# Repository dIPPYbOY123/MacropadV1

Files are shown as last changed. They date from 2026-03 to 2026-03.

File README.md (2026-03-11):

# MacropadV1

MacropadV1 is a custom-designed 6-key mechanical macropad featuring a rotary encoder, an OLED display, and RGB lighting. It's powered by the Seeed Xiao RP2040 and running KMK firmware.

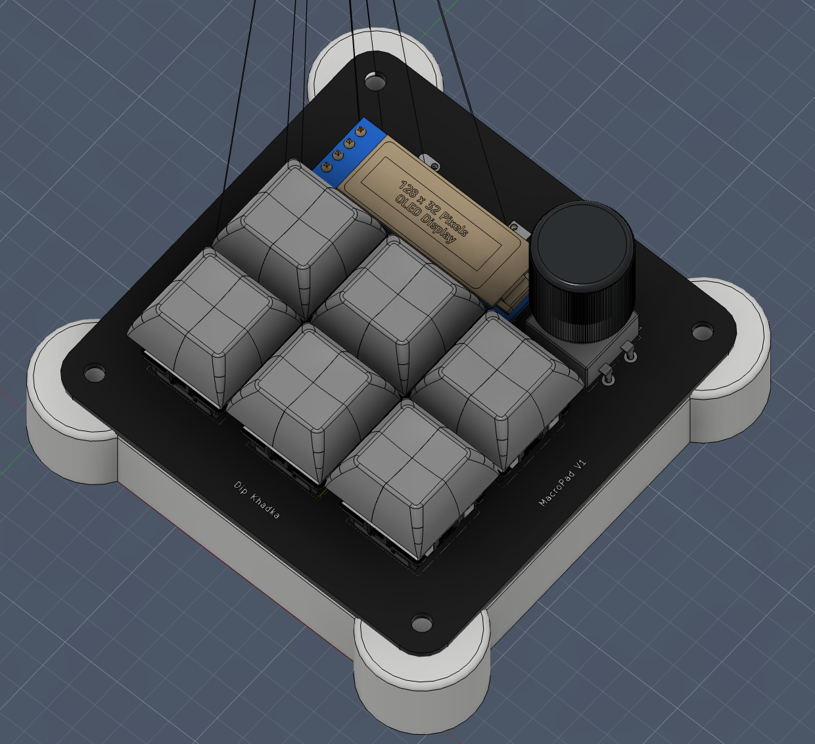
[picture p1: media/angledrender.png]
Macropad Render


## Features

- **6 Mechanical Switches**: MX-style switches.
- **Rotary Encoder**: Smooth scrolling and volume control.
- **OLED Display (128x32)**: Real-time feedback on layers, status, and custom animations.
- **7 Addressable RGB LEDs**: Fully customizable underglow and per-key lighting.
- **Compact Design**: Custom-designed 3D printable case for minimalistic vibe.
- **KMK Firmware**: Easily customizable using Python.

## Bill of Materials (BOM)

| Component | Quantity | Specification |
| :--- | :---: | :--- |
| **Microcontroller** | 1 | Seeed Xiao RP2040 |
| **Switches** | 6 | MX-style Mechanical Switches |
| **Keycaps** | 6 | MX-compatible Keycaps |
| **Rotary Encoder** | 1 | EC11 Encoder with Push Button |
| **OLED Display** | 1 | 0.91" 128x32 I2C OLED |
| **Diodes** | 6 | 1N4148 Through-hole Diodes |
| **RGB LEDs** | 7 | SK6812 Mini-E |
| **PCB** | 1 | Custom MacropadV1 PCB |
| **Hardware** | 4 | M3 x 16mm Screws |
| **Case** | 1 | 3D Printed Case |

### Case Design
Designed in Autodesk Fusion, the project includes a custom 3D printable case designed for a sleek, low-profile look.

| Case Angled View | Case Back View |
| :---: | :---: |
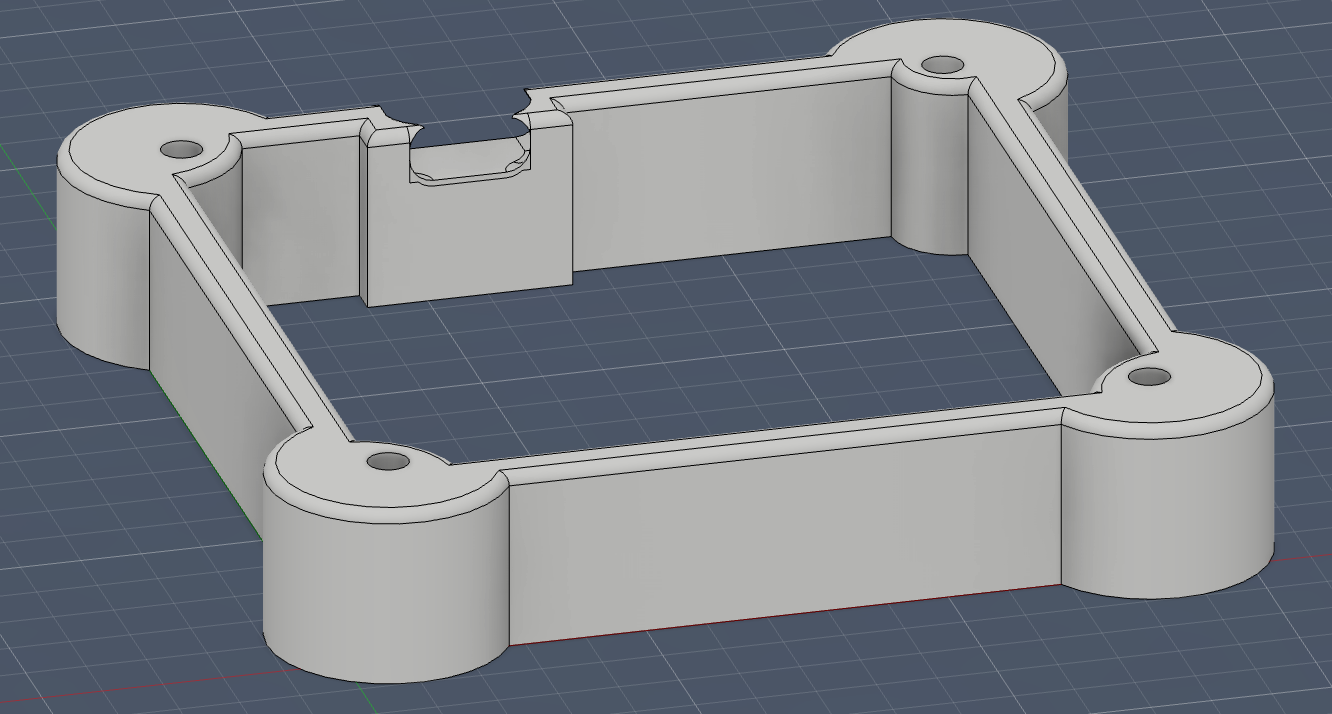
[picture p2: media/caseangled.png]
Case Angled View
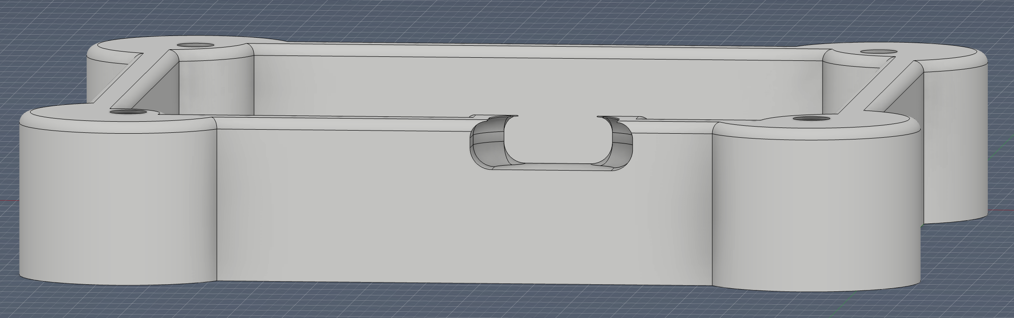
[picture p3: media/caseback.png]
Case Back View
|  |  |

## Firmware

MacropadV1 runs on **KMK Firmware**, a feature-rich keyboard firmware written in CircuitPython.

### Keymap Configuration
The default keymap includes dedicated layers for media control, macros (Copy/Paste/Save), and RGB lighting effects.

- **Layer 0**: Media controls, Copy/Paste/Cut macros, Screen Snipping.
- **Layer 1**: Navigation and Select All macros.
- **Layer 2**: RGB Lighting controls (Mode, Brightness, Color).

The rotary encoder is mapped to volume control by default.

## PCB & Electronics

The PCB has been designed in KiCad.

### PCB Layout
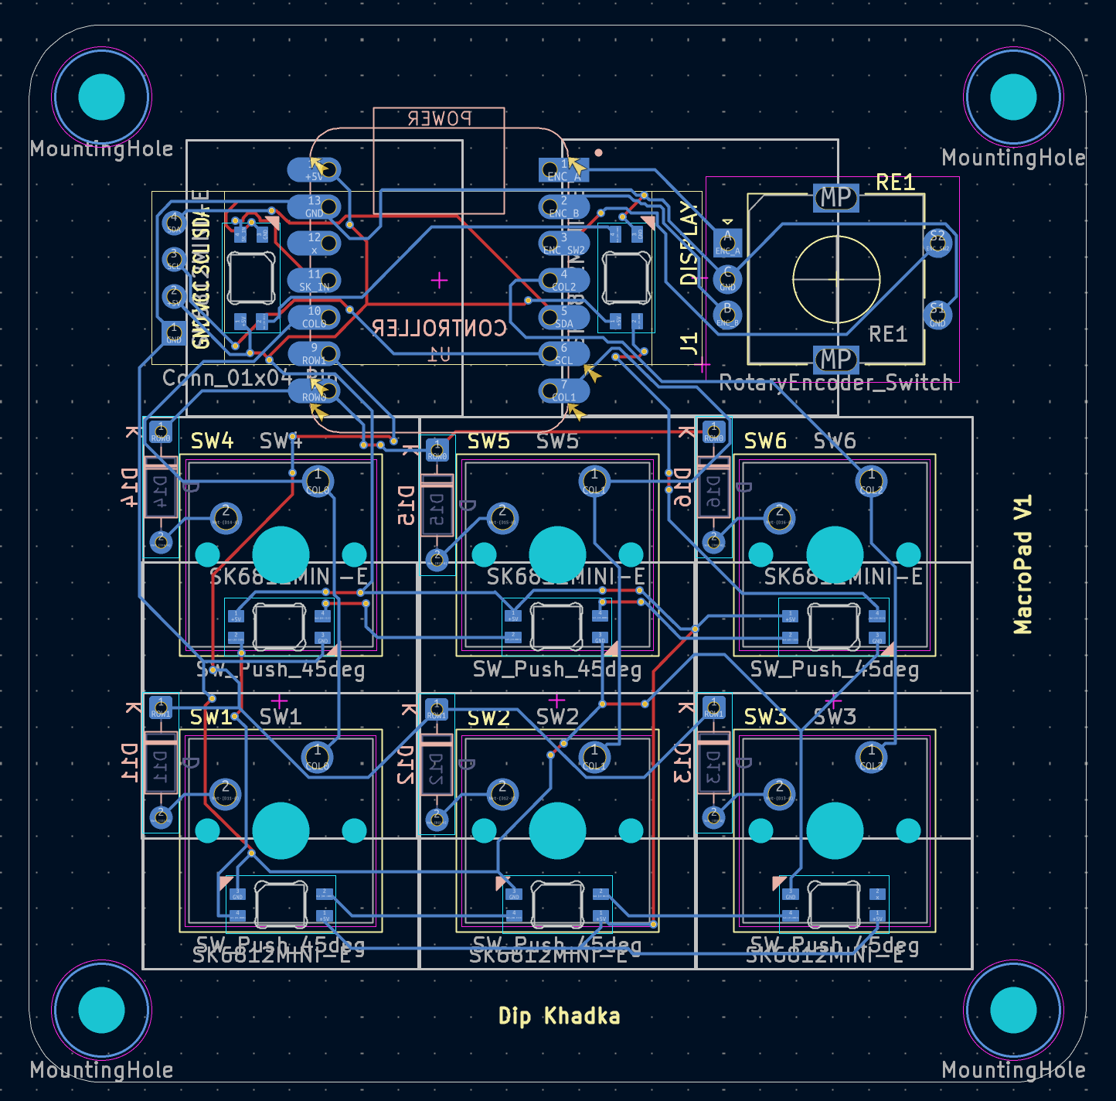
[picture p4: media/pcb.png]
PCB Layout


### 3D Visualizations
| Front | Back |
| :---: | :---: |
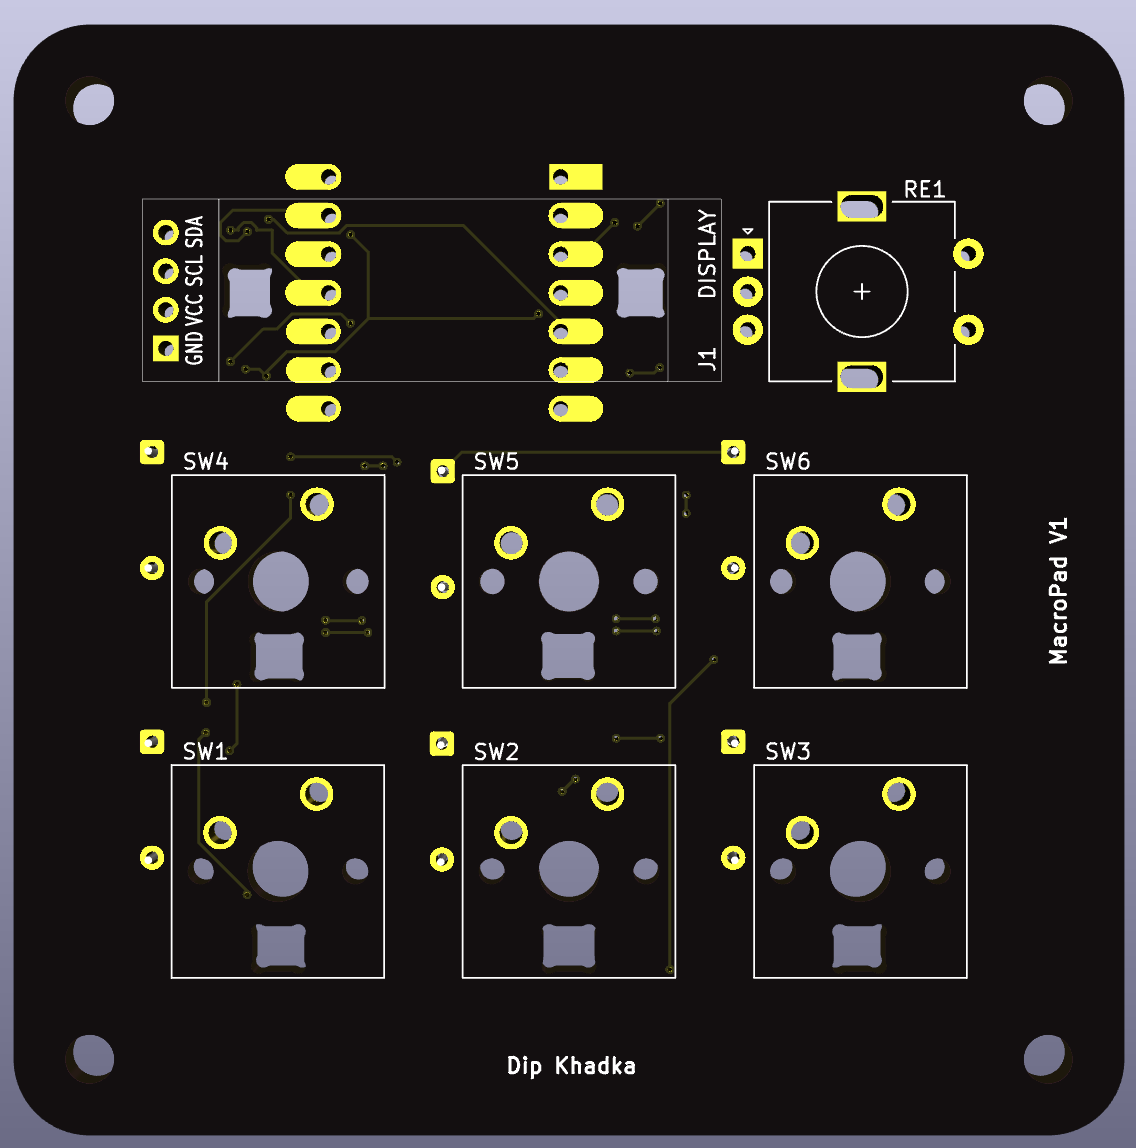
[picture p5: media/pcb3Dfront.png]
PCB Front
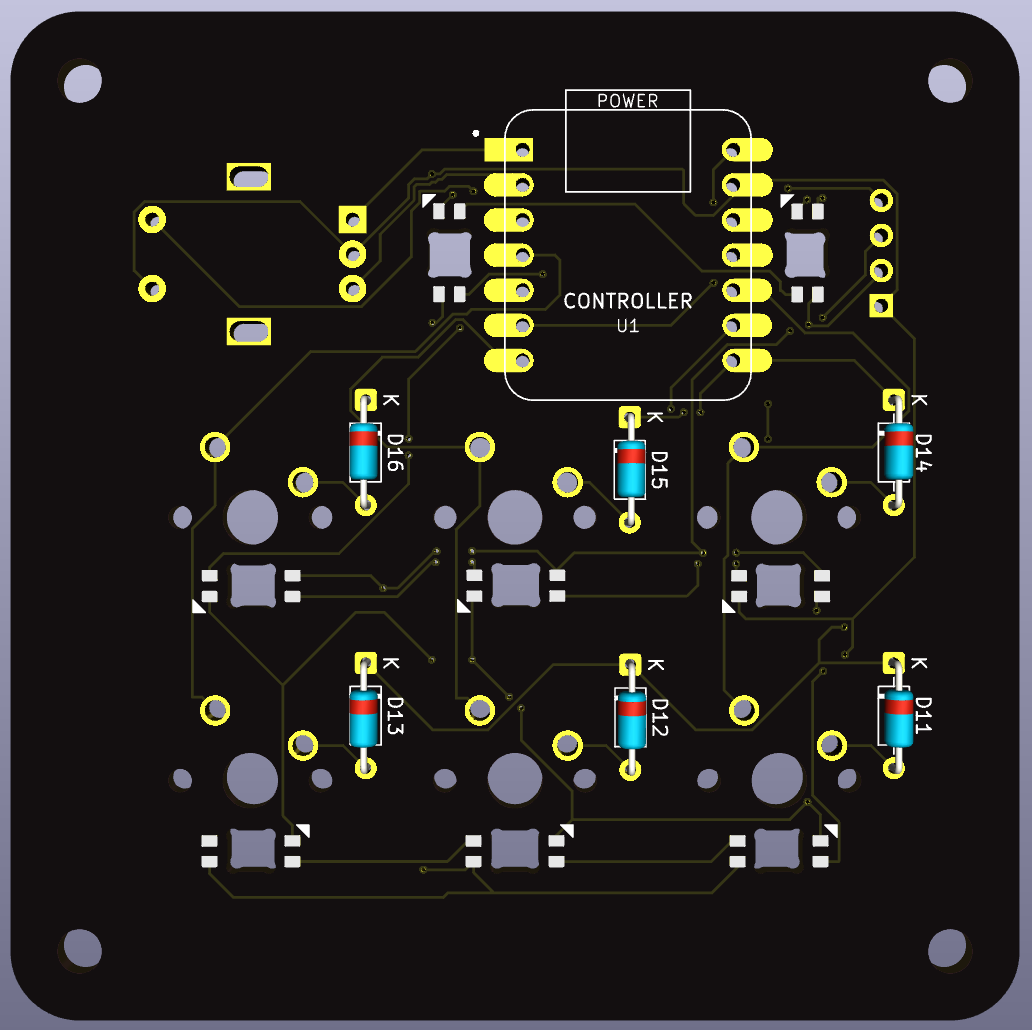
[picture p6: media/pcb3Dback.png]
PCB Back
|  |  |

### Schematic
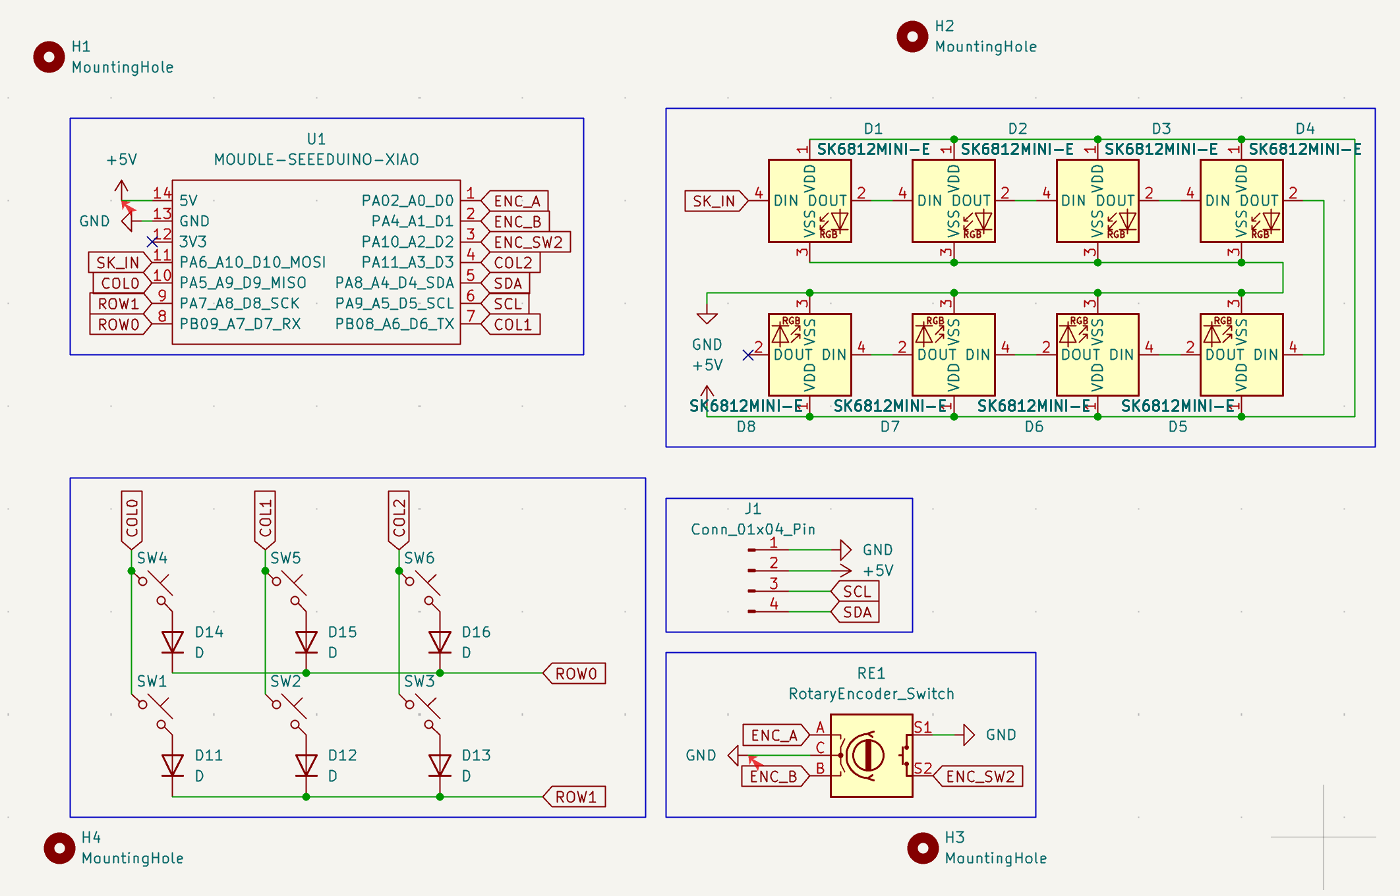
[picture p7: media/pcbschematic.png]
Schematic


## Project Structure

- `firmware/`: KMK configuration (`main.py`)
- `pcb/`: KiCad project files
- `cad/`: 3D design files for the case (STLs/Step)
- `media/`: Project images and documentation assets

---
Designed by **Dip Khadka**

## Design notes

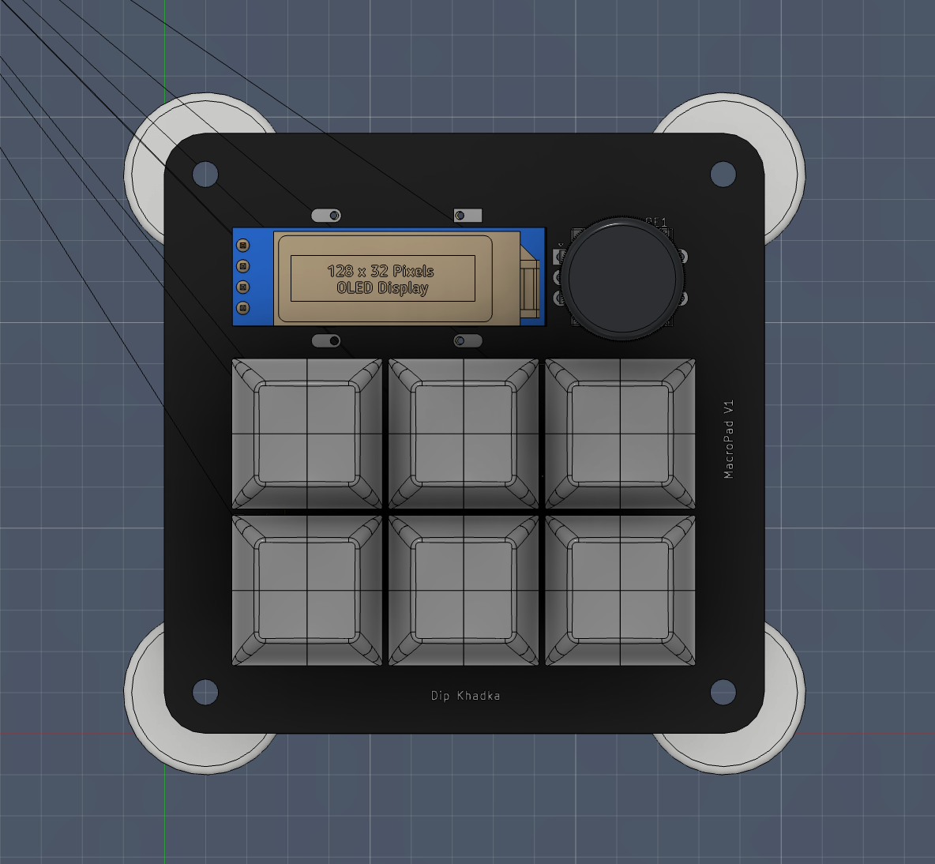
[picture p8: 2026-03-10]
media/topdownrender.png

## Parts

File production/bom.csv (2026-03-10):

Designator | Footprint | Quantity | Value | LCSC Part #
D1, D2, D3, D4, D5, D6, D7, D8 | MX_SK6812MINI-E_REV | 8 | SK6812MINI-E
D11, D12, D13, D14, D15, D16 | D_DO-35_SOD27_P7.62mm_Horizontal | 6 | D
J1 | SSD1306-0.91-OLED-4pin-128x32 | 1 | Conn_01x04_Pin
RE1 | RotaryEncoder_Alps_EC11E-Switch_Vertical_H20mm | 1 | RotaryEncoder_Switch
SW1, SW2, SW3, SW4, SW5, SW6 | SW_Cherry_MX_1.00u_PCB | 6 | SW_Push_45deg
U1 | XIAO-Generic-Hybrid-14P-2.54-21X17.8MM | 1 | MOUDLE-SEEEDUINO-XIAO

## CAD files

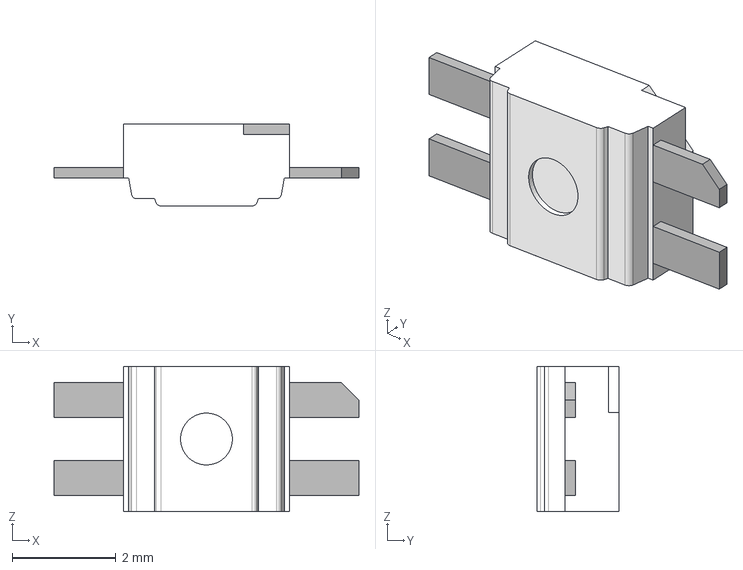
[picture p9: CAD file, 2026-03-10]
cad/SK6812MINI-E.step
5.88 x 1.58 x 2.80 mm

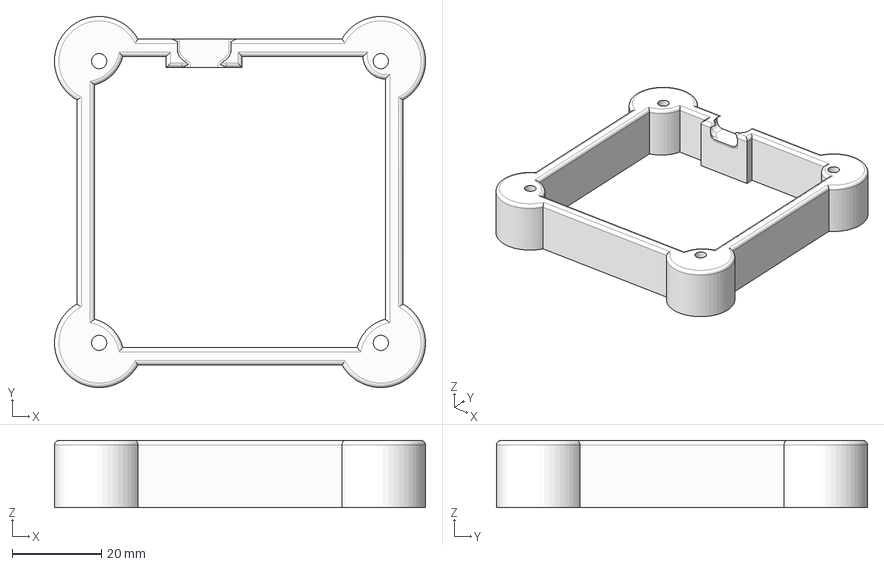
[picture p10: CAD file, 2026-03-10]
production/Case.step
83.0 x 83.0 x 15.0 mm

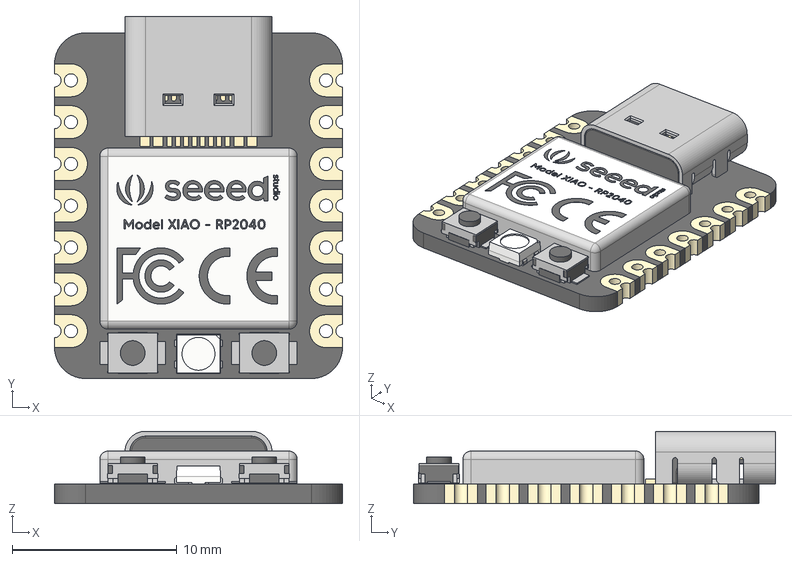
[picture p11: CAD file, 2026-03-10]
cad/Seeed_Studio_XIAO_RP2040_v26.step
17.5 x 22.0 x 4.40 mm
type-c v2
smd_button v3
DOUT
DIN
VSS
VDD
smd_button v3(Mirror)

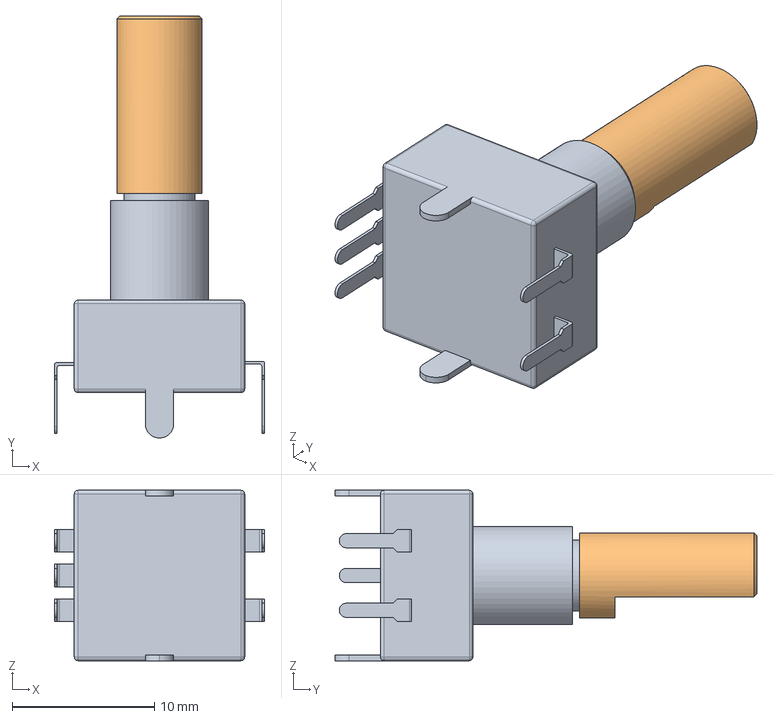
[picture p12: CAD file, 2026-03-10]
cad/RotaryEncoder_Alps_EC11E-Switch_Vertical_H20mm.step
14.8 x 29.7 x 12.0 mm

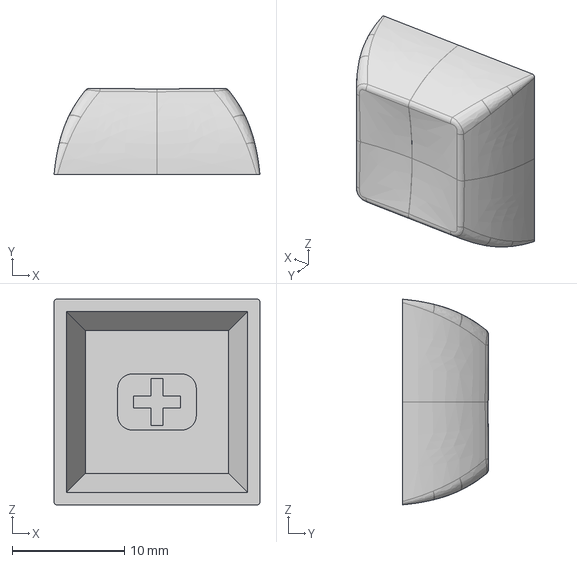
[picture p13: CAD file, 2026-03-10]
cad/DSA_Keycap_CherryMX.step
18.3 x 7.69 x 18.3 mm

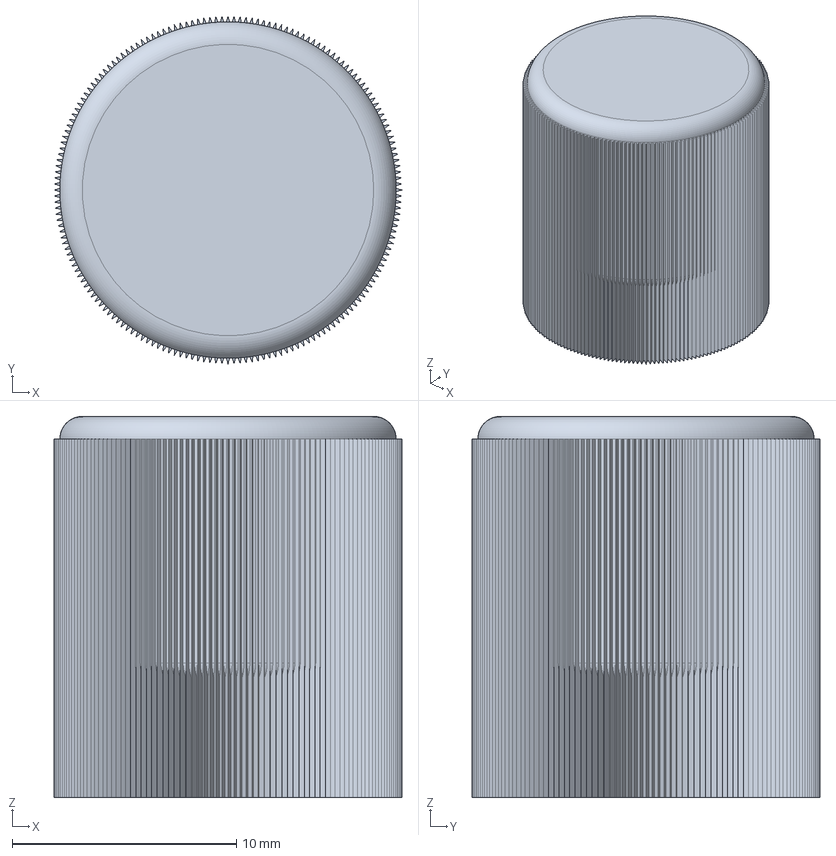
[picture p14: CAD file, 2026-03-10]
cad/SplashPad Case - Knob.step
15.5 x 15.5 x 17.0 mm

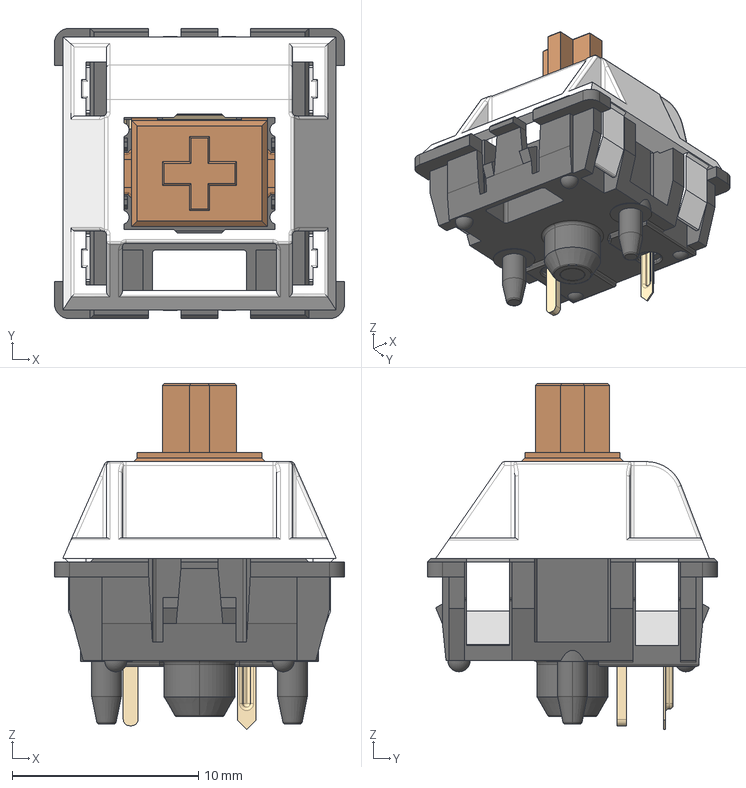
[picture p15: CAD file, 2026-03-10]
cad/MX_Switch.step
15.6 x 15.6 x 18.6 mm

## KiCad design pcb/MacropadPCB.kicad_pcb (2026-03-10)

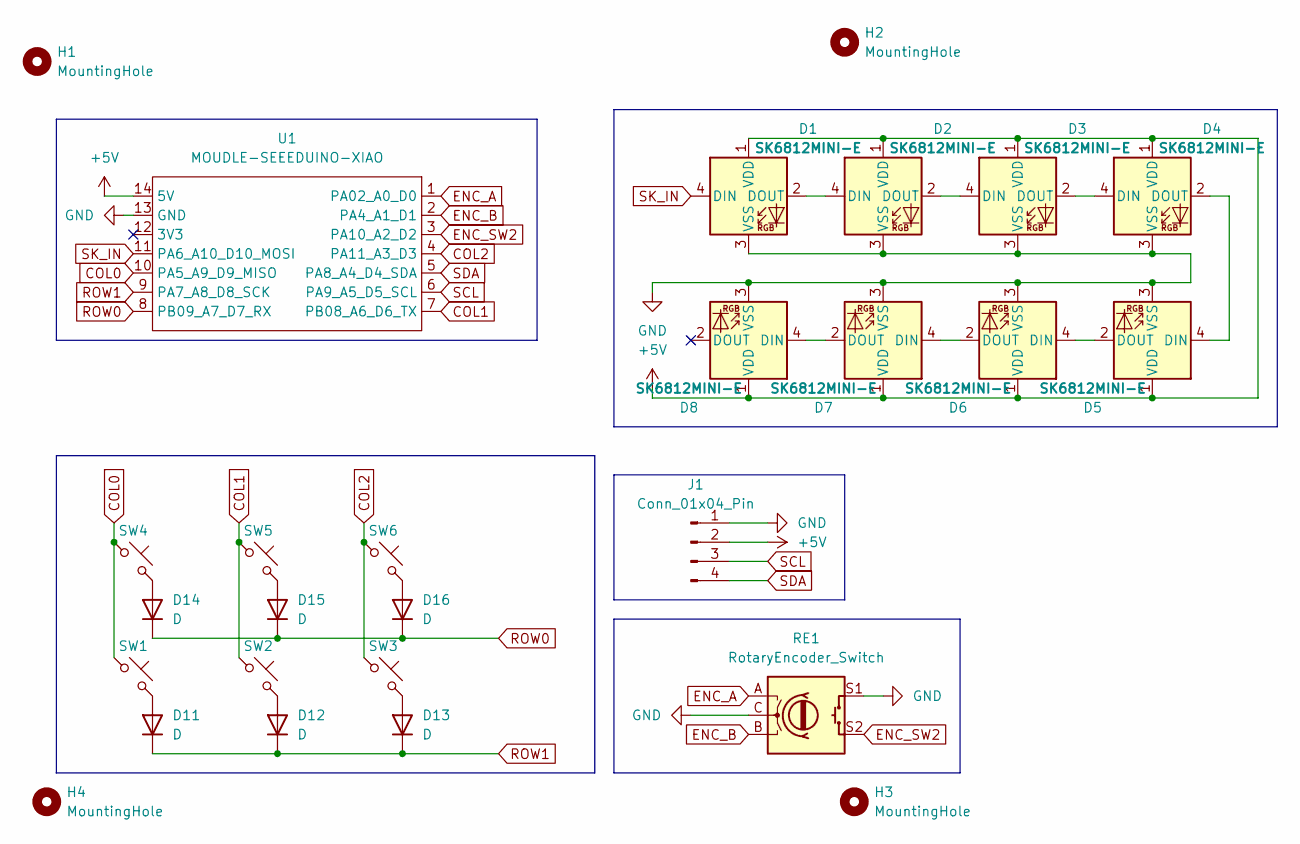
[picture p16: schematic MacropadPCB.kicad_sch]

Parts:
D1, D2, D3, D4, D5, D6, D7, D8: SK6812MINI-E; MX_SK6812MINI-E_REV
D11, D12, D13, D14, D15, D16: D; D_DO-35_SOD27_P7.62mm_Horizontal
H1, H2, H3, H4: MountingHole; MountingHole_3.2mm_M3
J1: Conn_01x04_Pin; SSD1306-0.91-OLED-4pin-128x32
RE1: RotaryEncoder_Switch; RotaryEncoder_Alps_EC11E-Switch_Vertical_H20mm
SW1, SW2, SW3, SW4, SW5, SW6: SW_Push_45deg; SW_Cherry_MX_1.00u_PCB
U1: MOUDLE-SEEEDUINO-XIAO; XIAO-Generic-Hybrid-14P-2.54-21X17.8MM

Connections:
+5V: D1.1 (VDD), D2.1 (VDD), D3.1 (VDD), D4.1 (VDD), D5.1 (VDD), D6.1 (VDD), D7.1 (VDD), D8.1 (VDD), J1.2, U1.14 (5V)
COL0: SW1.1, SW4.1, U1.10 (PA5_A9_D9_MISO)
COL1: SW2.1, SW5.1, U1.7 (PB08_A6_D6_TX)
COL2: SW3.1, SW6.1, U1.4 (PA11_A3_D3)
ENC_A: RE1.A, U1.1 (PA02_A0_D0)
ENC_B: RE1.B, U1.2 (PA4_A1_D1)
ENC_SW2: RE1.S2, U1.3 (PA10_A2_D2)
GND: D1.3 (VSS), D2.3 (VSS), D3.3 (VSS), D4.3 (VSS), D5.3 (VSS), D6.3 (VSS), D7.3 (VSS), D8.3 (VSS), J1.1, RE1.C, RE1.S1, U1.13 (GND)
unnamed: D1.2 (DOUT), D2.4 (DIN)
unnamed: D2.2 (DOUT), D3.4 (DIN)
unnamed: D3.2 (DOUT), D4.4 (DIN)
unnamed: D4.2 (DOUT), D5.4 (DIN)
unnamed: D5.2 (DOUT), D6.4 (DIN)
unnamed: D6.2 (DOUT), D7.4 (DIN)
unnamed: D7.2 (DOUT), D8.4 (DIN)
unnamed: D11.2 (A), SW1.2
unnamed: D12.2 (A), SW2.2
unnamed: D13.2 (A), SW3.2
unnamed: D14.2 (A), SW4.2
unnamed: D15.2 (A), SW5.2
unnamed: D16.2 (A), SW6.2
ROW0: D14.1 (K), D15.1 (K), D16.1 (K), U1.8 (PB09_A7_D7_RX)
ROW1: D11.1 (K), D12.1 (K), D13.1 (K), U1.9 (PA7_A8_D8_SCK)
SCL: J1.3, U1.6 (PA9_A5_D5_SCL)
SDA: J1.4, U1.5 (PA8_A4_D4_SDA)
SK_IN: D1.4 (DIN), U1.11 (PA6_A10_D10_MOSI)

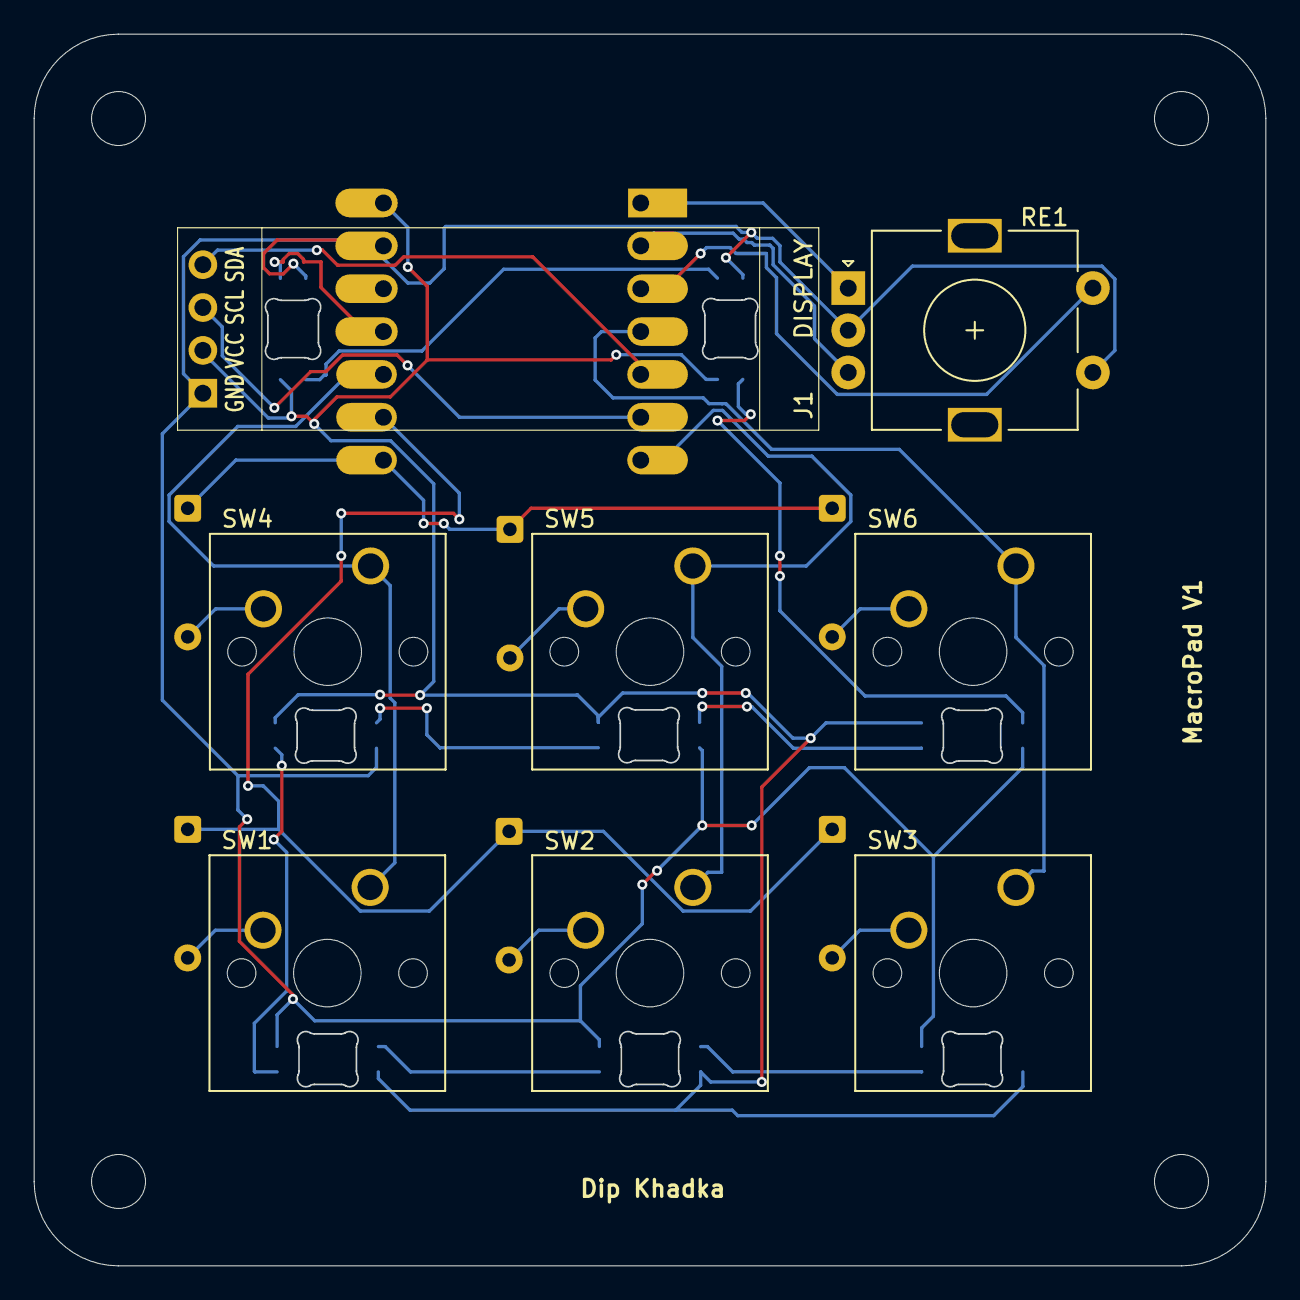
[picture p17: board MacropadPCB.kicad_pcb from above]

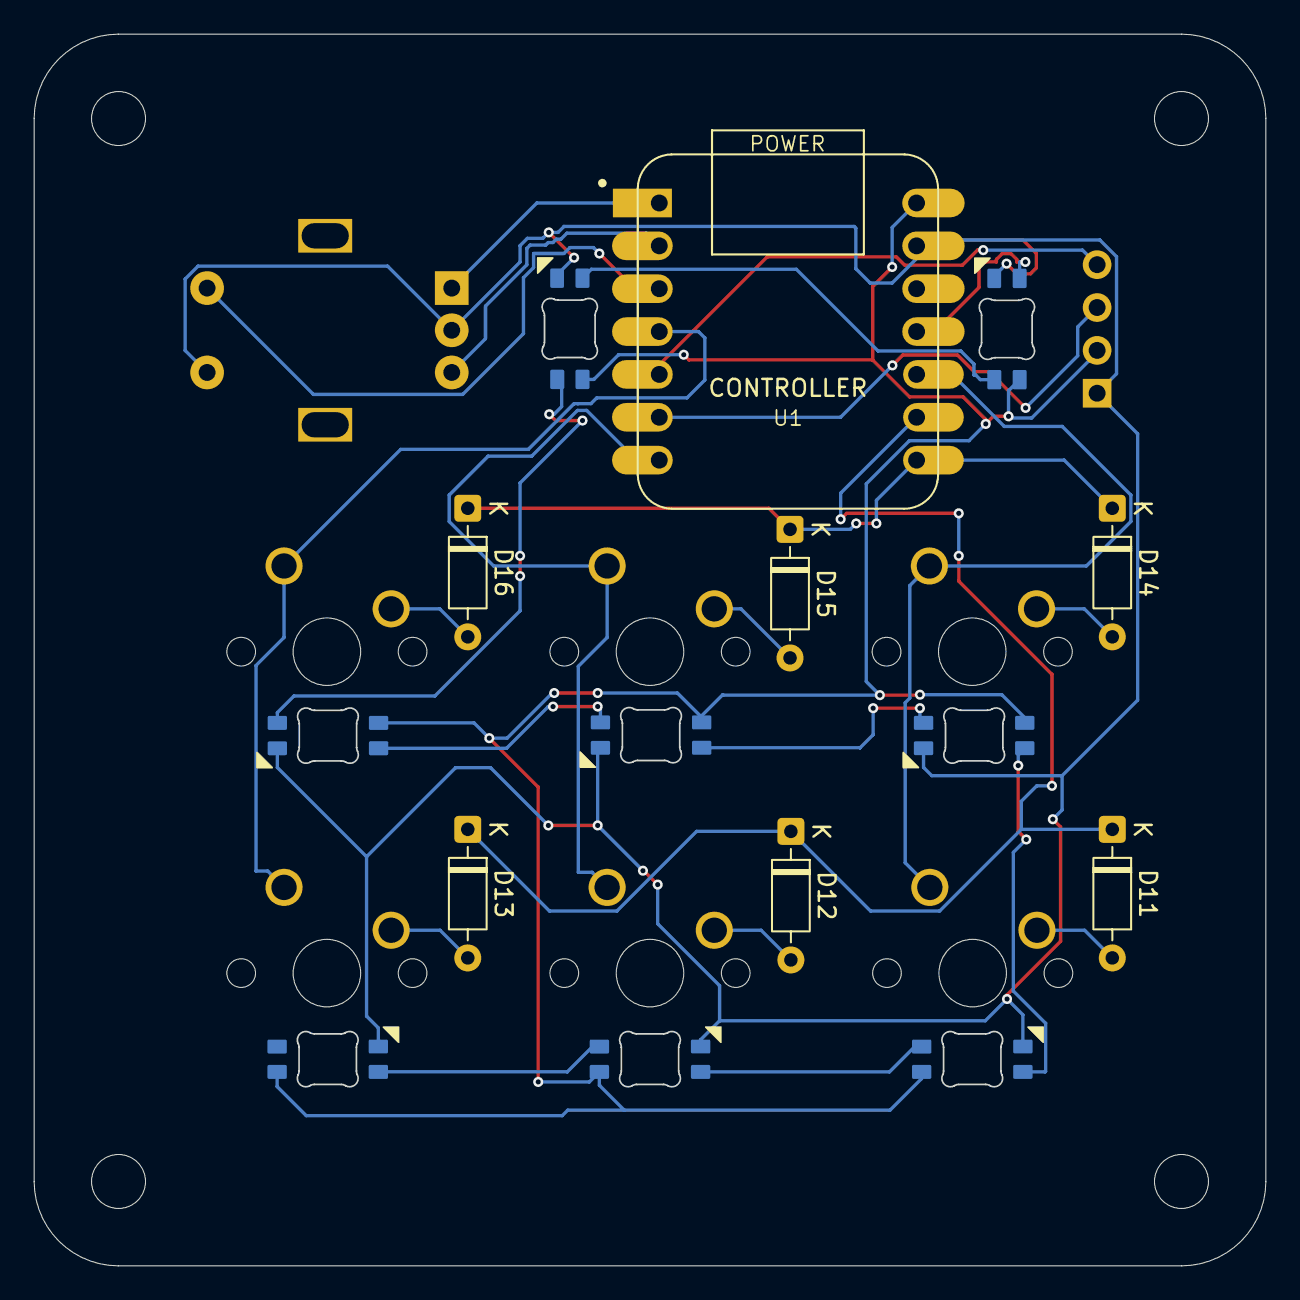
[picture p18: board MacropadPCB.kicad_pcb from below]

Board: 2 copper layers, 73.0 x 73.0 mm, 27 parts (7 on the bottom side), 26 nets.

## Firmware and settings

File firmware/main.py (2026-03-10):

import board
import busio
import time
from adafruit_ssd1306 import SSD1306_I2C

from kmk.kmk_keyboard import KMKKeyboard
from kmk.keys import KC
from kmk.scanners.keypad import KeysScanner
from kmk.scanners import DiodeOrientation

from kmk.modules.layers import Layers
from kmk.modules.macros import Press, Release, Tap, Macros
from kmk.modules.encoder import EncoderHandler

from kmk.extensions.rgb import RGB

keyboard = KMKKeyboard()

# Display Pins: D4 (SDA), D5 (SCL)
i2c = busio.I2C(board.D5, board.D4)

macros = Macros()
encoder_handler = EncoderHandler()

keyboard.modules.append(encoder_handler)
keyboard.modules.append(macros)
keyboard.modules.append(Layers())

# Matrix Configuration (3x2 grid)
keyboard.col_pins = (board.D6, board.D5, board.D4)
keyboard.row_pins = (board.D7, board.D8)
keyboard.diode_orientation = DiodeOrientation.COL2ROW

# Rotary Encoder Rotation: Pin 1 (D0), Pin 2 (D1)
# Encoder Button: Pin 4 (D3)
encoder_handler.pins = ((board.D0, board.D1, board.D3),)

# RGB Lighting: Pin 3 (D2), 7 Pixels
rgb = RGB(pixel_pin=board.D2, num_pixels=7)
keyboard.extensions.append(rgb)

# --- OLED Multi-View / App System ---

class DisplayManager(SSD1306_I2C):
    def __init__(self, *args, **kwargs):
        super().__init__(*args, **kwargs)
        self.current_app = 0
        self.apps = ["STATUS", "MACROS", "ABOUT"]
        self.active_layer = 0
        self.last_update = 0.0

    def next_app(self):
        self.current_app = (self.current_app + 1) % len(self.apps)
        self.refresh()

    def on_layer_change(self, layer: int):
        self.active_layer = layer
        self.refresh()

    def refresh(self):
        self.fill(0)
        app_name = self.apps[self.current_app]
        
        # Header
        self.text(f"--- {app_name} ---", 15, 0, 1)

        if app_name == "STATUS":
            self.text(f"LAYER: {self.active_layer}", 0, 16, 1)
            self.text(f"RGB: {'ON' if rgb.enabled else 'OFF'}", 64, 16, 1)
        
        elif app_name == "MACROS":
            macros_list = [
                ["Copy", "Paste", "Cut"],
                ["Undo", "Redo", "Snp"],
                ["Mode", "Hue", "Tog"]
            ]
            current_macros = macros_list[self.active_layer]
            self.text(f"{current_macros[0]} {current_macros[1]} {current_macros[2]}", 0, 16, 1)
            
        elif app_name == "ABOUT":
            self.text("Macropad V1", 0, 12, 1)
            self.text("by Dip Khadka", 0, 22, 1)

        self.show()

    def during_runtime_tick(self):
        # Refresh every 2 seconds if needed for stats or animations
        if time.monotonic() - self.last_update > 2:
            self.last_update = time.monotonic()
            # self.refresh() # Enable if dynamic content is added

display = DisplayManager(128, 32, i2c)  
keyboard.extensions.append(display)  

# Keymap Customization
# We'll use a Macro to cycle through OLED apps
# Trigger: We'll set the Encoder Button (D3) to cycle apps on a double click or special layer
# For now, let's add a dedicated View Cycle key to Layer 0

keyboard.keymap = [
    [ # Layer 0: Default
        KC.MUTE,     KC.Macro(Press(KC.LCTRL), Tap(KC.C), Release(KC.LCTRL)), 
        KC.Macro(Press(KC.LCTRL), Tap(KC.V), Release(KC.LCTRL)), KC.Macro(Press(KC.LCTRL), Tap(KC.X), Release(KC.LCTRL)),
        KC.MO(1),    KC.LT(2, KC.RGB_TOG), 
    ],
    [ # Layer 1: Navigation/Macros
        KC.UNDO,     KC.REDO,
        KC.Macro(Press(KC.LGUI), Press(KC.LSHIFT), Tap(KC.S), Release(KC.LSHIFT), Release(KC.LGUI)), KC.SELECT_ALL,
        KC.TRNS,     KC.TRNS,
    ],
    [ # Layer 2: RGB Control
        KC.RGB_MODE_PLAIN, KC.RGB_MODE_BREATHE,
        KC.RGB_MODE_RAINBOW, KC.RGB_MODE_SWIRL,
        KC.RGB_SAI, KC.RGB_SAD,
    ]
]

# Encoder Mapping: Volume, Navigation, RGB
# Encoder click (D3) now cycles the OLED apps!
encoder_handler.map = [
    [ (KC.VOLU, KC.VOLD, KC.NO) ], # App cycling handled by custom logic below
    [ (KC.PGUP, KC.PGDN, KC.NO) ],
    [ (KC.RGB_HUI, KC.RGB_HUD, KC.NO) ]
]

# Custom Encoder Button Logic to cycle Apps
def encoder_button_callback(event):
    if event.pressed:
        display.next_app()

keyboard.before_matrix_scan.append(lambda x: None) # Placeholder

# Using a custom class to intercept the encoder button
class AppCycler(EncoderHandler):
    def on_button_pressed(self, index):
        display.next_app()

# Re-initialize encoder with cycling logic
# Actually, KMK handles this better with individual key overrides,
# but for a multi-view app, triggering display.next_app() directly is best.

# Let's map the encoder button to a special key that we intercept
APP_CYCLE = KC.Macro(Tap(KC.F24)) # Dummy key to trigger cycle

encoder_handler.map = [
    [ (KC.VOLU, KC.VOLD, APP_CYCLE) ], 
    [ (KC.PGUP, KC.PGDN, APP_CYCLE) ],
    [ (KC.RGB_HUI, KC.RGB_HUD, APP_CYCLE) ]
]

# Intercept APP_CYCLE to change view
class AppSwitchExtension:
    def on_runtime_tick(self, keyboard):
        pass
    def before_matrix_scan(self, keyboard):
        pass
    def after_matrix_scan(self, keyboard):
        pass
    def before_hid_send(self, keyboard):
        pass
    def after_hid_send(self, keyboard):
        pass
    def on_powersave_enable(self, keyboard):
        pass
    def on_powersave_disable(self, keyboard):
        pass

# Simpler way: Use KMK's handler
def cycle_apps_handler(keyboard, key, is_pressed):
    if is_pressed and key == APP_CYCLE:
        display.next_app()
        return False # Don't send F24 to PC
    return True

keyboard.process_key = cycle_apps_handler

# Initial Display
display.refresh()

if __name__ == '__main__':
    keyboard.go()

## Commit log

2026-03-10 Initial commit with README and project files
    [DSA_Keycap_CherryMX.step, MX_Switch.step, MacropadPCB.kicad_pcb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]
2026-03-10 Add detailed Bill of Materials to README
2026-03-10 Finalize BOM: remove cable, update screw size and case description
2026-03-10 Update project images and final documentation refinements
    [Case.step, MacropadPCB.kicad_pcb, MacropadPCB.kicad_sch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]
2026-03-10 Update README to use new 3D PCB image filenames
2026-03-11 Fix punctuation and enhance case design description
    Added a period to the end of a sentence and clarified the case design description.
